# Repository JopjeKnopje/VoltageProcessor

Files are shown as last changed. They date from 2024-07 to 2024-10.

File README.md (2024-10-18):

# VoltageProcessor

A eurorack module that outputs the sum and difference of the two inputs, you can also add a constant DC offset to the summing output.

## Motivation
My beatstep's pitch output cannot go lower than 2V, the vco I'm using has a range of approximately 0-5V so I needed a way to subtract the 2V off of the pitch output.
This module does just that, I indend to just use 1 CV input with the beatstep and the constant DC offset at -2V to achieve an output of 0V with a 2V input.

### Notes
This is my second KiCad project in a long time so the routing is not the best :)
Measured the current consumption at 1mA @ +12V and 7mA @ -12V

### Falstad simulation
https://tinyurl.com/26u5qrzk

## Bill of materials
|Reference|Value |Qty |
|---|---|---|
|C1,C2,C3,C4|0.1uF |4 |
|C5,C6 |47uF |2 |
|J1,J2,J4,J5|PJ301M-12 |4 |
|J3 |Eurorack power |1 |
|R1,R2,R3,R4,R5,R6,R7,R8,R9,R10,R11,R12|100k |12 |
|R13,R14  |1k |2 |
|R15,R16  |10k |2 |
|RV1,RV2,RV3|100k |3 |
|U1 |TL074 |1 |

## Schematic

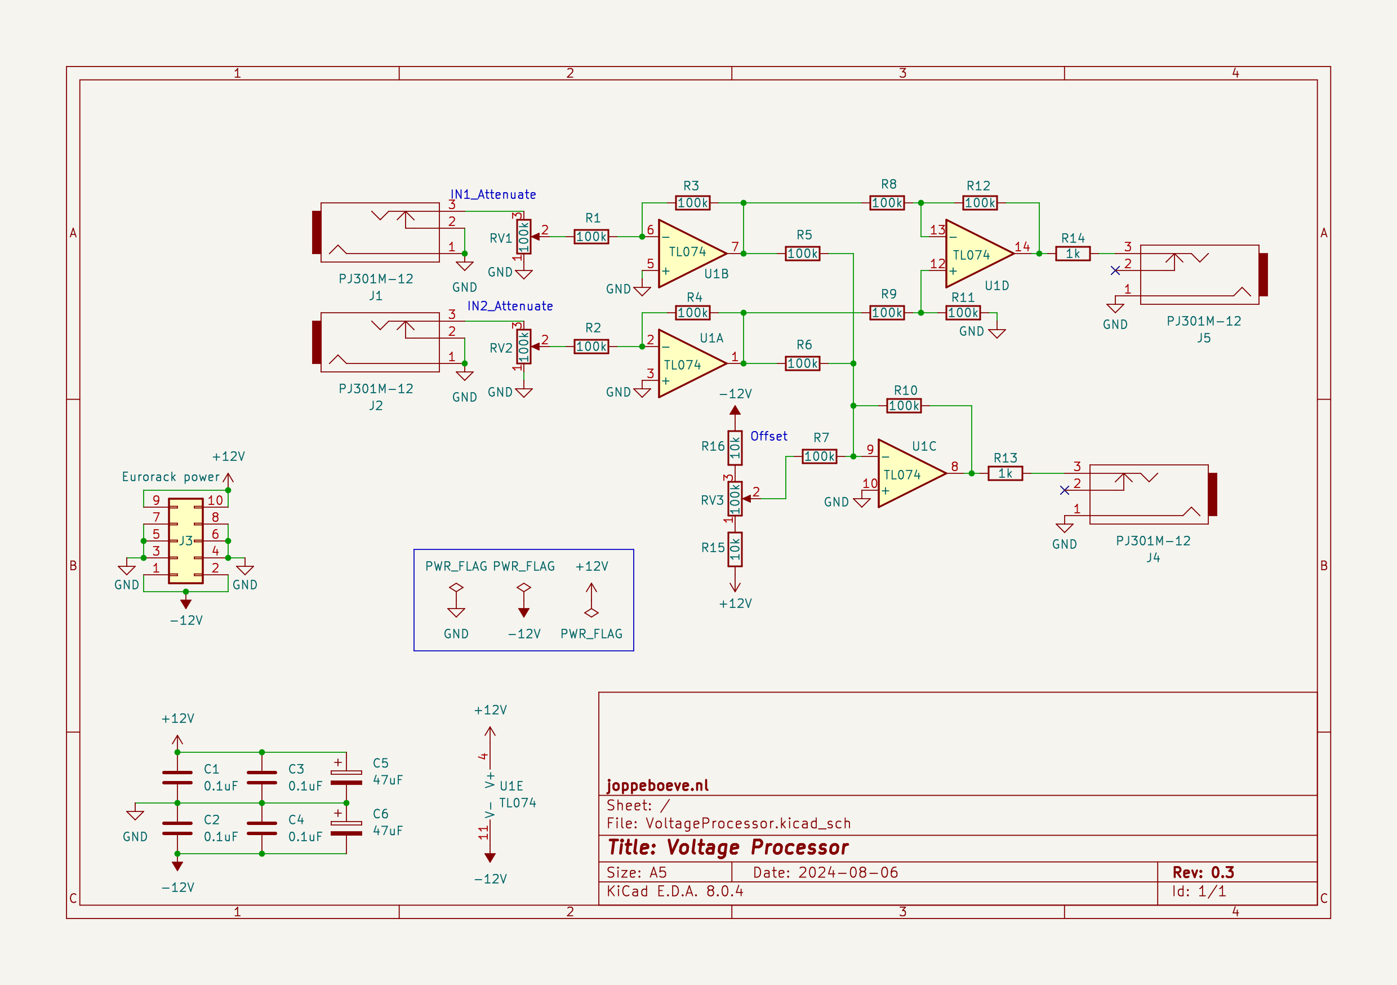
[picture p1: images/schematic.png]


## KiCad renders
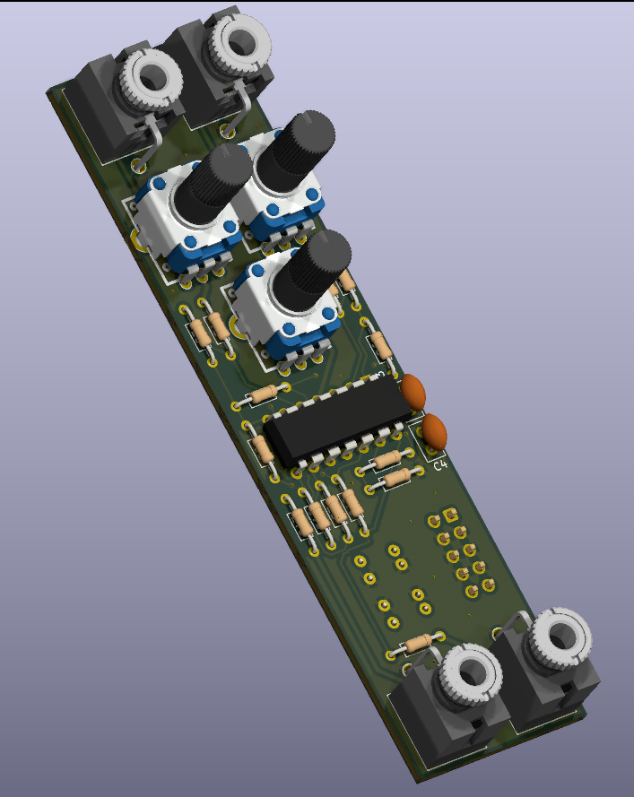
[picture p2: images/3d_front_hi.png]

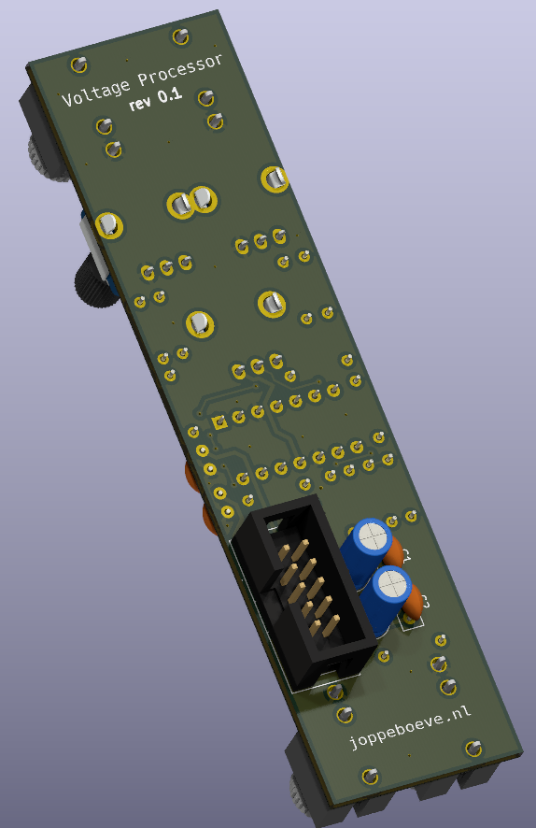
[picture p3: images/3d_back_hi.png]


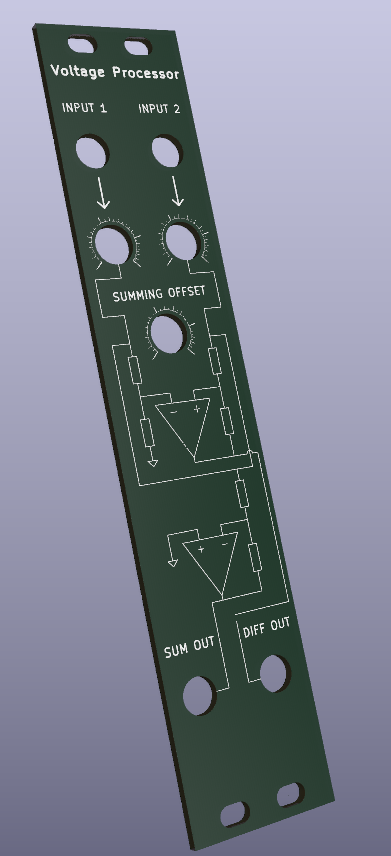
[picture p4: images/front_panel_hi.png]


### rev 0.2 -> 0.3 patches
- DC Offset potmeter range is now `+-10` instead of the rail-rail voltage.

### rev 0.1 -> 0.2 patches
- Flip eurorack power connector around y-axis, I currently use a flipped power cable as a workaround.
- Switch `U1B` and `U1B` terminals by adding jumper wire and cutting trace.
- J4 and J5 output should be on pin 3 instead of pin 2. fix by adding jumper wire.

## Todo
- [x] All of the `rev 0.1 patches`
- [ ] Fix jack hole should be 6mm instead of 5.3mm.
- [x] DC Offset potmeter compensate for opamp rail-rail offset which is around 1.3v
- [x] Add polarity symbol in C5 and C6.
- [x] Switch RV1 and RV2 twisting direction.
- [ ] Think about more ergonomic potmeter position.
- [x] Front panel
- [x] Produce and test rev 0.1

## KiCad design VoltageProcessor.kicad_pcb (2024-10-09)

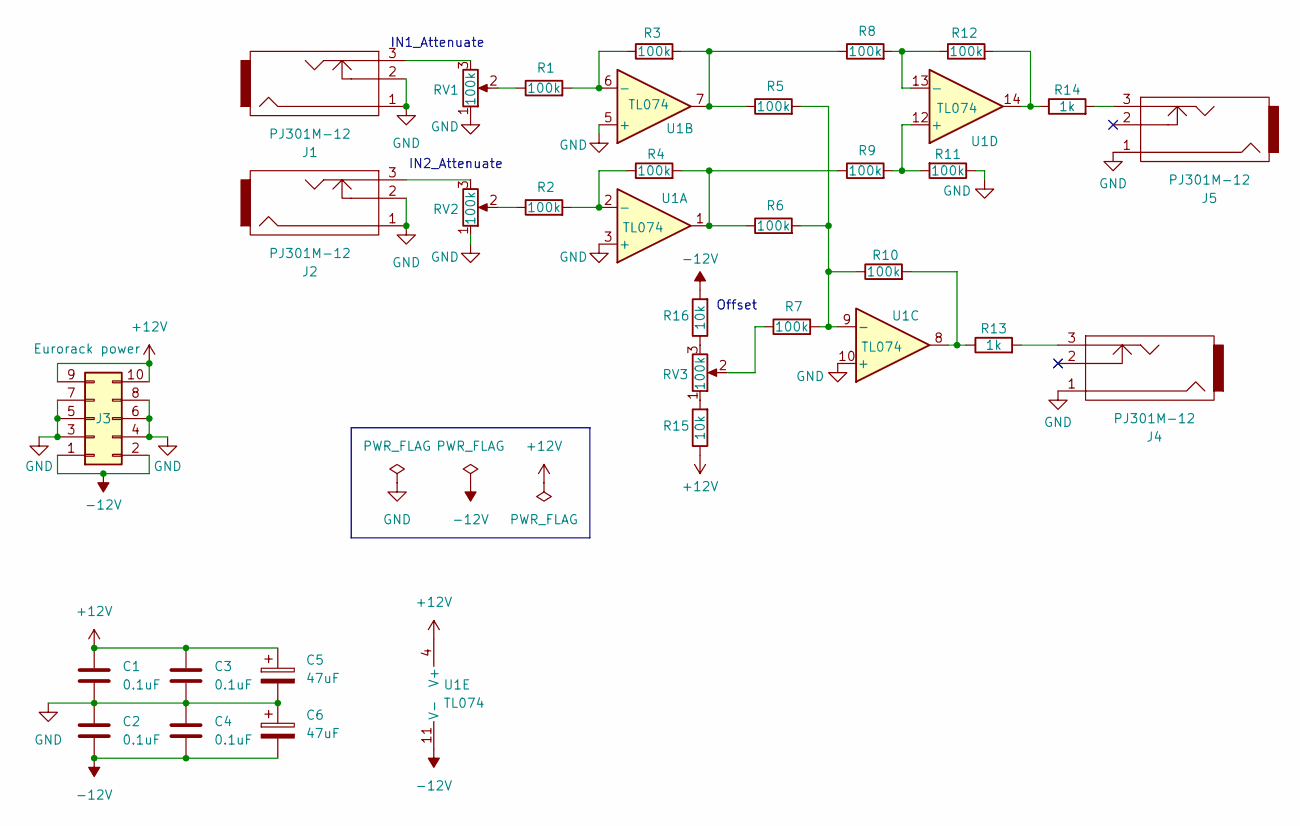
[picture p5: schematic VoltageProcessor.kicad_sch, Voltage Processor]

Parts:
C1, C2, C3, C4: 0.1uF; C_Disc_D5.0mm_W2.5mm_P2.50mm
C5, C6: 47uF; CP_Radial_D5.0mm_P2.00mm
J1, J2, J4, J5: PJ301M-12
J3: Eurorack power; IDC-Header_2x05_P2.54mm_Vertical
R1, R2, R3, R4, R5, R6, R7, R8, R9, R10, R11, R12: 100k; R_Axial_DIN0204_L3.6mm_D1.6mm_P7.62mm_Horizontal
R13, R14: 1k; R_Axial_DIN0204_L3.6mm_D1.6mm_P7.62mm_Horizontal
R15, R16: 10k; R_Axial_DIN0204_L3.6mm_D1.6mm_P7.62mm_Horizontal
RV1, RV2, RV3: 100k; trimmer_alps-rk09k1130ah1
U1: TL074; DIP-14_W7.62mm

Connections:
+12V: C1.1, C3.1, C5.1, J3.9, J3.10, R15.1, U1.4 (V+)
-12V: C2.2, C4.2, C6.2, J3.1, J3.2, R16.2, U1.11 (V-)
GND: C1.2, C2.1, C3.2, C4.1, C5.2, C6.1, J1.1, J1.2, J2.1, J2.2, J3.3, J3.4, J3.5, J3.6, J3.7, J3.8, J4.1, J5.1, R11.1, RV1.1, RV2.1, U1.3 (+), U1.5 (+), U1.10 (+)
unnamed: J1.3, RV1.3
unnamed: J2.3, RV2.3
unnamed: J4.3, R13.2
unnamed: J5.3, R14.2
unnamed: R1.1, RV1.2
unnamed: R2.1, RV2.2
unnamed: R3.2, R5.1, R8.1, U1.7
unnamed: R4.2, R6.1, R9.1, U1.1
unnamed: R7.1, RV3.2
unnamed: R10.2, R13.1, U1.8
unnamed: R12.2, R14.1, U1.14
unnamed: R15.2, RV3.1
unnamed: R16.1, RV3.3
unnamed: R2.2, R4.1, U1.2 (-)
unnamed: R1.2, R3.1, U1.6 (-)
unnamed: R5.2, R6.2, R7.2, R10.1, U1.9 (-)
unnamed: R9.2, R11.2, U1.12 (+)
unnamed: R8.2, R12.1, U1.13 (-)

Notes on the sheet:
IN1_Attenuate
Offset
IN2_Attenuate

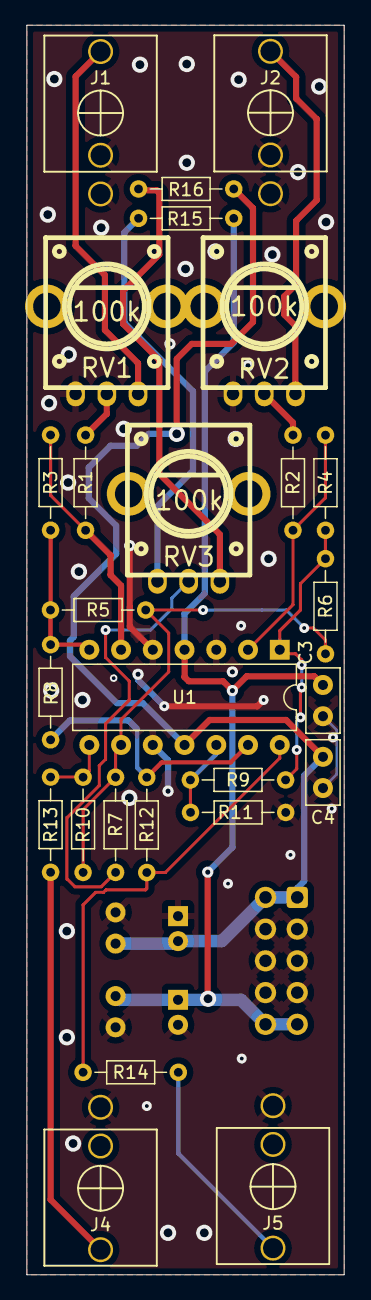
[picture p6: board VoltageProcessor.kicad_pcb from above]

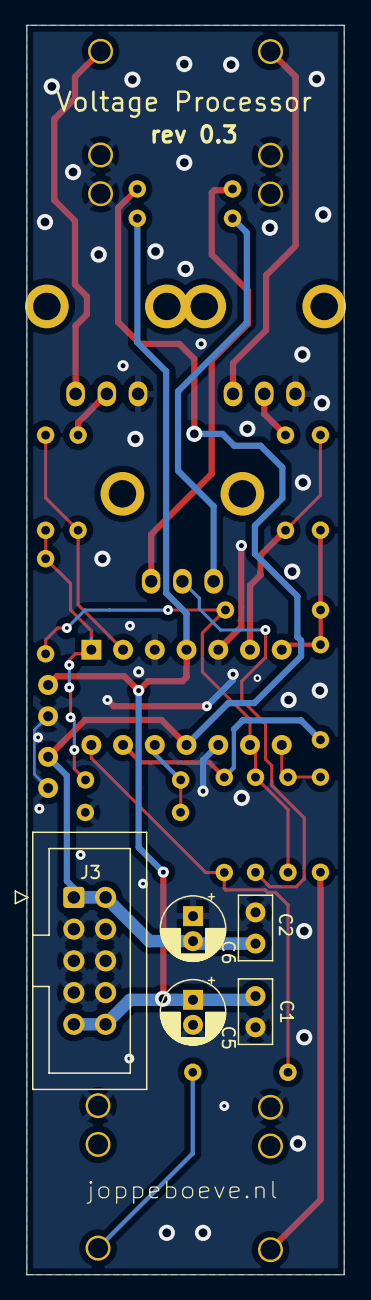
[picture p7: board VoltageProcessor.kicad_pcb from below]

Board: 2 copper layers, 25.4 x 100.0 mm, 31 parts (5 on the bottom side), 21 nets.

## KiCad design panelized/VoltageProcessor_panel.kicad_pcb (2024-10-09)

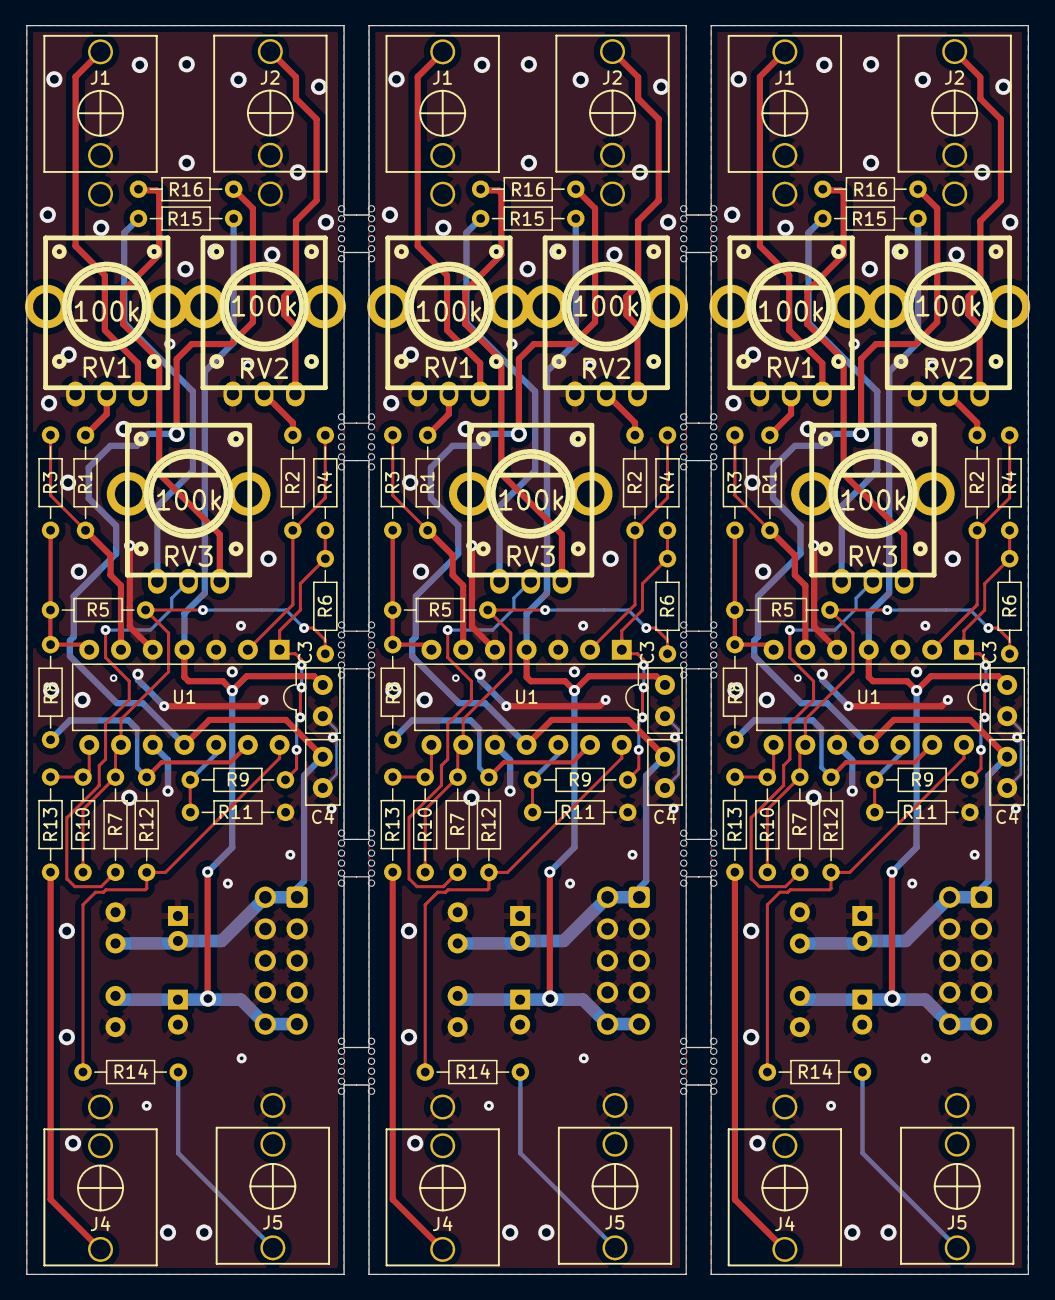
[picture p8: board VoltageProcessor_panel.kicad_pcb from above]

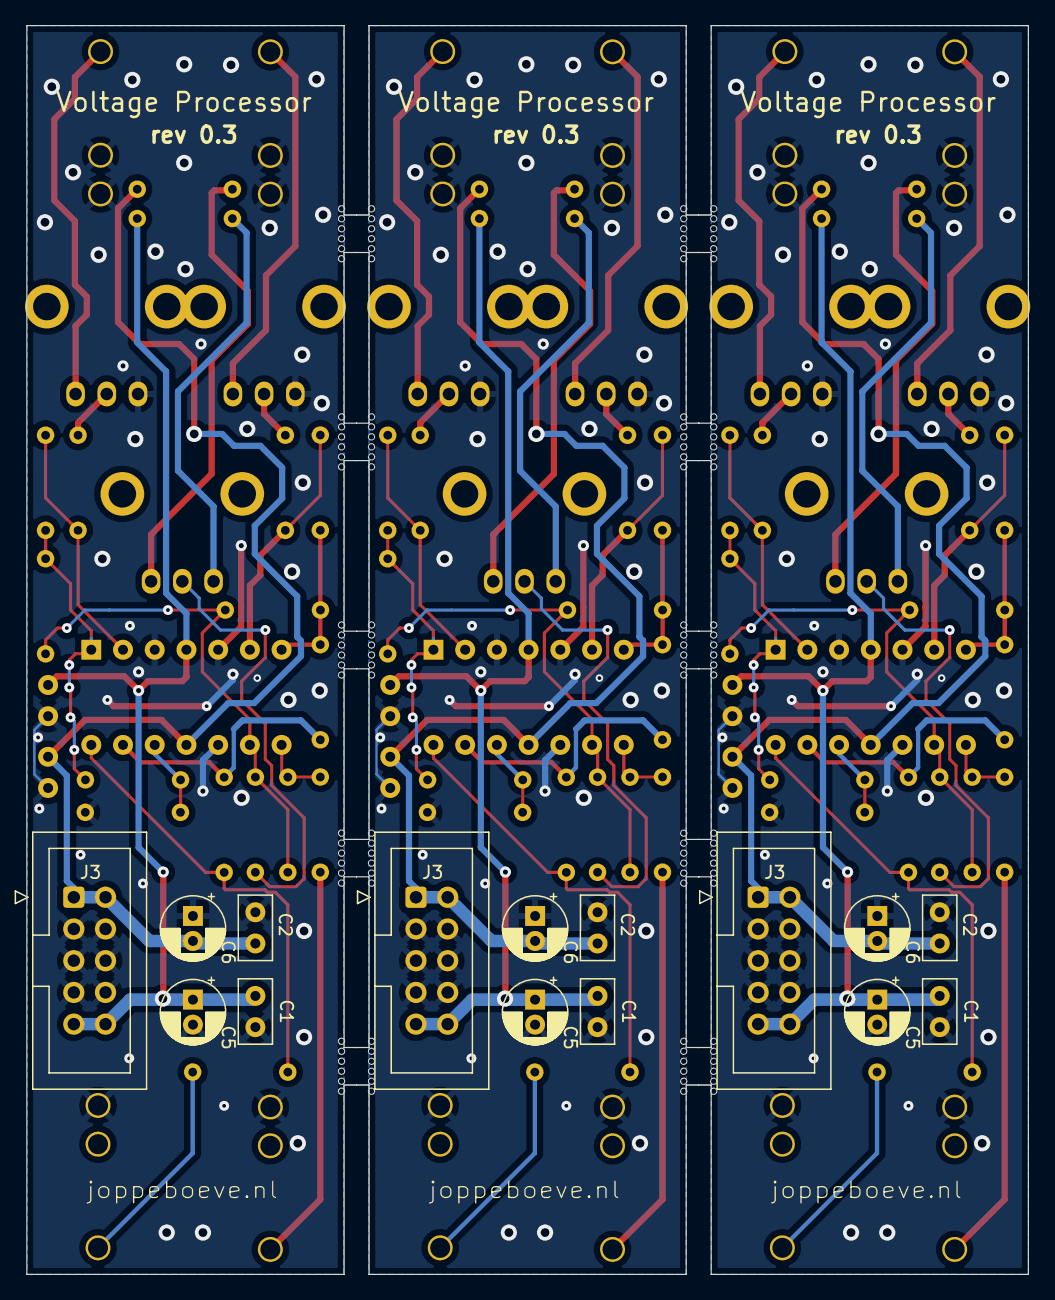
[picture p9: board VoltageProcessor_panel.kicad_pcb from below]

Board: 2 copper layers, 80.2 x 100.0 mm, 213 parts (15 on the bottom side), 63 nets.

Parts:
C1, C1#2, C1#3, C2, C2#2, C2#3, C3, C3#2, C3#3, C4, C4#2, C4#3: 0.1uF; C_Disc_D5.0mm_W2.5mm_P2.50mm
C5, C5#2, C5#3, C6, C6#2, C6#3: 47uF; CP_Radial_D5.0mm_P2.00mm
J1, J1#2, J1#3, J2, J2#2, J2#3, J4, J4#2, J4#3, J5, J5#2, J5#3: PJ301M-12
J3, J3#2, J3#3: Eurorack power; IDC-Header_2x05_P2.54mm_Vertical
KiKit_MB_1_1, KiKit_MB_1_2, KiKit_MB_1_3, KiKit_MB_1_4, KiKit_MB_1_5, KiKit_MB_1_6, KiKit_MB_2_1, KiKit_MB_2_2, KiKit_MB_2_3, KiKit_MB_2_4, KiKit_MB_2_5, KiKit_MB_2_6, KiKit_MB_3_1, KiKit_MB_3_2, KiKit_MB_3_3, KiKit_MB_3_4, KiKit_MB_3_5, KiKit_MB_3_6, KiKit_MB_4_1, KiKit_MB_4_2, KiKit_MB_4_3, KiKit_MB_4_4, KiKit_MB_4_5, KiKit_MB_4_6, KiKit_MB_5_1, KiKit_MB_5_2, KiKit_MB_5_3, KiKit_MB_5_4, KiKit_MB_5_5, KiKit_MB_5_6, KiKit_MB_6_1, KiKit_MB_6_2, KiKit_MB_6_3, KiKit_MB_6_4, KiKit_MB_6_5, KiKit_MB_6_6, KiKit_MB_7_1, KiKit_MB_7_2, KiKit_MB_7_3, KiKit_MB_7_4, KiKit_MB_7_5, KiKit_MB_7_6, KiKit_MB_8_1, KiKit_MB_8_2, KiKit_MB_8_3, KiKit_MB_8_4, KiKit_MB_8_5, KiKit_MB_8_6, KiKit_MB_9_1, KiKit_MB_9_2, KiKit_MB_9_3, KiKit_MB_9_4, KiKit_MB_9_5, KiKit_MB_9_6, KiKit_MB_10_1, KiKit_MB_10_2, KiKit_MB_10_3, KiKit_MB_10_4, KiKit_MB_10_5, KiKit_MB_10_6, KiKit_MB_11_1, KiKit_MB_11_2, KiKit_MB_11_3, KiKit_MB_11_4, KiKit_MB_11_5, KiKit_MB_11_6, KiKit_MB_12_1, KiKit_MB_12_2, KiKit_MB_12_3, KiKit_MB_12_4, KiKit_MB_12_5, KiKit_MB_12_6, KiKit_MB_13_1, KiKit_MB_13_2, KiKit_MB_13_3, KiKit_MB_13_4, KiKit_MB_13_5, KiKit_MB_13_6, KiKit_MB_14_1, KiKit_MB_14_2, KiKit_MB_14_3, KiKit_MB_14_4, KiKit_MB_14_5, KiKit_MB_14_6, KiKit_MB_15_1, KiKit_MB_15_2, KiKit_MB_15_3, KiKit_MB_15_4, KiKit_MB_15_5, KiKit_MB_15_6, KiKit_MB_16_1, KiKit_MB_16_2, KiKit_MB_16_3, KiKit_MB_16_4, KiKit_MB_16_5, KiKit_MB_16_6, KiKit_MB_17_1, KiKit_MB_17_2, KiKit_MB_17_3, KiKit_MB_17_4, KiKit_MB_17_5, KiKit_MB_17_6, KiKit_MB_18_1, KiKit_MB_18_2, KiKit_MB_18_3, KiKit_MB_18_4, KiKit_MB_18_5, KiKit_MB_18_6, KiKit_MB_19_1, KiKit_MB_19_2, KiKit_MB_19_3, KiKit_MB_19_4, KiKit_MB_19_5, KiKit_MB_19_6, KiKit_MB_20_1, KiKit_MB_20_2, KiKit_MB_20_3, KiKit_MB_20_4, KiKit_MB_20_5, KiKit_MB_20_6: NPTH
R1, R1#2, R1#3, R2, R2#2, R2#3, R3, R3#2, R3#3, R4, R4#2, R4#3, R5, R5#2, R5#3, R6, R6#2, R6#3, R7, R7#2, R7#3, R8, R8#2, R8#3, R9, R9#2, R9#3, R10, R10#2, R10#3, R11, R11#2, R11#3, R12, R12#2, R12#3: 100k; R_Axial_DIN0204_L3.6mm_D1.6mm_P7.62mm_Horizontal
R13, R13#2, R13#3, R14, R14#2, R14#3: 1k; R_Axial_DIN0204_L3.6mm_D1.6mm_P7.62mm_Horizontal
R15, R15#2, R15#3, R16, R16#2, R16#3: 10k; R_Axial_DIN0204_L3.6mm_D1.6mm_P7.62mm_Horizontal
RV1, RV1#2, RV1#3, RV2, RV2#2, RV2#3, RV3, RV3#2, RV3#3: 100k; trimmer_alps-rk09k1130ah1
U1, U1#2, U1#3: TL074; DIP-14_W7.62mm

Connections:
Board_0-+12V: C1#2.1, C3#2.1, C5.1, J3#3.9, J3#3.10, R15#2.1, U1#2.4 (V+)
Board_0--12V: C2#3.2, C4#2.2, C6#2.2, J3#3.1, J3#3.2, R16#2.2, U1#2.11 (V-)
Board_0-GND: C1#2.2, C2#3.1, C3#2.2, C4#2.1, C5.2, C6#2.1, J1#2.1, J1#2.2, J2.1, J2.2, J3#3.3, J3#3.4, J3#3.5, J3#3.6, J3#3.7, J3#3.8, J4#3.1, J5#2.1, R11#2.1, RV1.1, RV2#2.1, U1#2.3 (+), U1#2.5 (+), U1#2.10 (+)
Board_0-Net-(J1-Pad3): J1#2.3, RV1.3
Board_0-Net-(J2-Pad3): J2.3, RV2#2.3
Board_0-Net-(J4-Pad3): J4#3.3, R13#2.2
Board_0-Net-(J5-Pad3): J5#2.3, R14#2.2
Board_0-Net-(R1-Pad1): R1.1, RV1.2
Board_0-Net-(R2-Pad1): R2#2.1, RV2#2.2
Board_0-Net-(R3-Pad2): R3#3.2, R5#2.1, R8#2.1, U1#2.7
Board_0-Net-(R4-Pad2): R4#2.2, R6#3.1, R9.1, U1#2.1
Board_0-Net-(R7-Pad1): R7#3.1, RV3.2
Board_0-Net-(R10-Pad2): R10#3.2, R13#2.1, U1#2.8
Board_0-Net-(R12-Pad2): R12.2, R14#2.1, U1#2.14
Board_0-Net-(R15-Pad2): R15#2.2, RV3.1
Board_0-Net-(R16-Pad1): R16#2.1, RV3.3
Board_0-Net-(U1A--): R2#2.2, R4#2.1, U1#2.2 (-)
Board_0-Net-(U1B--): R1.2, R3#3.1, U1#2.6 (-)
Board_0-Net-(U1C--): R5#2.2, R6#3.2, R7#3.2, R10#3.1, U1#2.9 (-)
Board_0-Net-(U1D-+): R9.2, R11#2.2, U1#2.12 (+)
Board_0-Net-(U1D--): R8#2.2, R12.1, U1#2.13 (-)
Board_1-+12V: C1.1, C3.1, C5#2.1, J3.9, J3.10, R15.1, U1.4 (V+)
Board_1--12V: C2#2.2, C4.2, C6.2, J3.1, J3.2, R16#3.2, U1.11 (V-)
Board_1-GND: C1.2, C2#2.1, C3.2, C4.1, C5#2.2, C6.1, J1#3.1, J1#3.2, J2#3.1, J2#3.2, J3.3, J3.4, J3.5, J3.6, J3.7, J3.8, J4.1, J5#3.1, R11.1, RV1#3.1, RV2#3.1, U1.3 (+), U1.5 (+), U1.10 (+)
Board_1-Net-(J1-Pad3): J1#3.3, RV1#3.3
Board_1-Net-(J2-Pad3): J2#3.3, RV2#3.3
Board_1-Net-(J4-Pad3): J4.3, R13#3.2
Board_1-Net-(J5-Pad3): J5#3.3, R14.2
Board_1-Net-(R1-Pad1): R1#3.1, RV1#3.2
Board_1-Net-(R2-Pad1): R2#3.1, RV2#3.2
Board_1-Net-(R3-Pad2): R3#2.2, R5.1, R8.1, U1.7
Board_1-Net-(R4-Pad2): R4#3.2, R6#2.1, R9#2.1, U1.1
Board_1-Net-(R7-Pad1): R7#2.1, RV3#3.2
Board_1-Net-(R10-Pad2): R10.2, R13#3.1, U1.8
Board_1-Net-(R12-Pad2): R12#3.2, R14.1, U1.14
Board_1-Net-(R15-Pad2): R15.2, RV3#3.1
Board_1-Net-(R16-Pad1): R16#3.1, RV3#3.3
Board_1-Net-(U1A--): R2#3.2, R4#3.1, U1.2 (-)
Board_1-Net-(U1B--): R1#3.2, R3#2.1, U1.6 (-)
Board_1-Net-(U1C--): R5.2, R6#2.2, R7#2.2, R10.1, U1.9 (-)
Board_1-Net-(U1D-+): R9#2.2, R11.2, U1.12 (+)
Board_1-Net-(U1D--): R8.2, R12#3.1, U1.13 (-)
Board_2-+12V: C1#3.1, C3#3.1, C5#3.1, J3#2.9, J3#2.10, R15#3.1, U1#3.4 (V+)
Board_2--12V: C2.2, C4#3.2, C6#3.2, J3#2.1, J3#2.2, R16.2, U1#3.11 (V-)
Board_2-GND: C1#3.2, C2.1, C3#3.2, C4#3.1, C5#3.2, C6#3.1, J1.1, J1.2, J2#2.1, J2#2.2, J3#2.3, J3#2.4, J3#2.5, J3#2.6, J3#2.7, J3#2.8, J4#2.1, J5.1, R11#3.1, RV1#2.1, RV2.1, U1#3.3 (+), U1#3.5 (+), U1#3.10 (+)
Board_2-Net-(J1-Pad3): J1.3, RV1#2.3
Board_2-Net-(J2-Pad3): J2#2.3, RV2.3
Board_2-Net-(J4-Pad3): J4#2.3, R13.2
Board_2-Net-(J5-Pad3): J5.3, R14#3.2
Board_2-Net-(R1-Pad1): R1#2.1, RV1#2.2
Board_2-Net-(R2-Pad1): R2.1, RV2.2
Board_2-Net-(R3-Pad2): R3.2, R5#3.1, R8#3.1, U1#3.7
Board_2-Net-(R4-Pad2): R4.2, R6.1, R9#3.1, U1#3.1
Board_2-Net-(R7-Pad1): R7.1, RV3#2.2
Board_2-Net-(R10-Pad2): R10#2.2, R13.1, U1#3.8
Board_2-Net-(R12-Pad2): R12#2.2, R14#3.1, U1#3.14
Board_2-Net-(R15-Pad2): R15#3.2, RV3#2.1
Board_2-Net-(R16-Pad1): R16.1, RV3#2.3
Board_2-Net-(U1A--): R2.2, R4.1, U1#3.2 (-)
Board_2-Net-(U1B--): R1#2.2, R3.1, U1#3.6 (-)
Board_2-Net-(U1C--): R5#3.2, R6.2, R7.2, R10#2.1, U1#3.9 (-)
Board_2-Net-(U1D-+): R9#3.2, R11#3.2, U1#3.12 (+)
Board_2-Net-(U1D--): R8#3.2, R12#2.1, U1#3.13 (-)

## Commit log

2024-07-26 IO Placement
    [VoltageProcessor.kicad_pcb, VoltageProcessor.kicad_sch]
2024-07-26 Pre route
    [VoltageProcessor.kicad_pcb, VoltageProcessor.kicad_sch]
2024-07-26 Done with routing but DRC issues
    [VoltageProcessor.kicad_pcb]
2024-07-26 Fix most DRC errors
    [VoltageProcessor.kicad_pcb]
2024-07-28 Add silkscreen text, and last DRC issues
    [VoltageProcessor.kicad_pcb, VoltageProcessor.kicad_sch]
2024-07-28 Add 3D models
    [VoltageProcessor.kicad_pcb]
2024-07-28 Connected input CV jack's switch to GND instead of NC Add schematic picture
    [VoltageProcessor.kicad_pcb, VoltageProcessor.kicad_sch]
2024-07-28 Add gerbers Add 3D model back in Add kikit makefile to generate panel
    [VoltageProcessor-B_Cu.gbl, VoltageProcessor-B_Mask.gbs, VoltageProcessor-B_Paste.gbp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]
2024-07-28 Add panelized files
    [VoltageProcessor_panel-B_Cu.gbl, VoltageProcessor_panel-B_Mask.gbs, VoltageProcessor_panel-B_Paste.gbp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]
2024-07-28 Add FrontPanel
    [FrontPanel.kicad_pcb]
2024-07-28 Add frontpanel gerbers
    [FrontPanel-B_Cu.gbl, FrontPanel-B_Mask.gbs, FrontPanel-B_Paste.gbp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]
2024-07-28 Change Makefile Add FrontPanel_panels
    [VoltageProcessor_panel.kicad_pcb]
2024-07-28 Actually add front_panel gebers
    [FrontPanel_panel-B_Cu.gbl, FrontPanel_panel-B_Mask.gbs, FrontPanel_panel-B_Paste.gbp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]
2024-08-02 Found some bugs while assembling the board
2024-08-05 Swapped `U1B` inputs to match that of `U1A`, so that it does work
    [VoltageProcessor.kicad_pcb, VoltageProcessor.kicad_sch]
2024-08-05 Switched `RV1` and `RV2`
    [VoltageProcessor.kicad_sch]
2024-08-05 Implemented fixes in schematic
    [VoltageProcessor.kicad_pcb, VoltageProcessor.kicad_sch]
2024-08-05 Remove all tracks
    [VoltageProcessor.kicad_pcb, VoltageProcessor.kicad_sch]
2024-08-05 New routing implenting the fixes for rev 0.1
    [VoltageProcessor.kicad_pcb]
2024-08-05 Went with old routing instead, with the fixes implemented in the PCB layout. Update README.md
    [VoltageProcessor.kicad_pcb, VoltageProcessor.kicad_sch]
2024-10-09 Add `R15` `R16` to DC Offset potmeter its range is now `+-10` instead of the `rail-rail` voltage. Add small changes in routing to accomodate the resistors. Add change text to `rev 0.3`
    [FrontPanel_panel-B_Mask.gbs, FrontPanel_panel-B_Paste.gbp, FrontPanel_panel-B_Silkscreen.gbo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]
2024-10-18 Change schematic page to `rev 0.3` Add BOM Change README
    [VoltageProcessor.kicad_sch, bom.csv]
